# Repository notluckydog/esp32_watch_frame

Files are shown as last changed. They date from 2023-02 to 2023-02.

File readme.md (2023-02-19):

### 1. 项目说明

项目初衷：

某天突然发现了GC9A01这款1.28英寸的圆形TFT屏幕，正好当时在学习ESP32以及LVGL这款开源嵌入式GUI库，于是加在一起，自然而然就想到了做一款圆形手表。

项目定位：

demo项目，本意是用来验证esp32是否能够GC9A01这款1.28英寸屏幕，以及LVGL学习板(虽然最后并没有使用LVGL来实现该项目)。

项目功能：

1. 开机动画：在上电时播放开机动画，初始化例如网络信息的获取在此阶段完成
2. 多级菜单：分为三级菜单(如果把主页面和功能选择页面放在一级的话就是两级页面)，能够正常地进入和退出菜单，并能能够使用页面上提供的功能。
3. 天气信息：提供从今天起的未来三天的天气信息，并且展示在页面上，按下next按键时，展示下一天的天气信息，最多三天，按下menu按键，返回上一级菜单。
4. 计时功能：正计时、番茄钟(项目中未实现)、闹钟(项目中未实现)，按下ok按键，开始或者暂停计时，按下next按键时，复位并停止计时，按下menu返回上一级菜单。
5. 游戏功能：内置一款谷歌恐龙小游戏(仅绘制页面以及实现部分基本逻辑，未验证是否可行)。
6. 视频播放：播放badapple动画(TF卡功能未实现暂且放弃)。
7. 功能设置：对背光、网络信息更新频率、是否开启闹钟进行调整(其中背光和网络信息调整是滑动条，开启关闭闹钟用的是按钮)。

### 2. 目录结构  

- doc      ---用来存放相关datasheet等文档
- hardware  ---用来存放硬件部分原理图和PCB等文件
  - name_CAM  :gerber文件，发给PCB板厂
  - name_PRJ :工程文件，原理图以及PCB文件等
  - name_BOM :物料文件
  - name_ASM :贴片文件，发送给贴片厂
- model      ---用来存放外壳或者其他模型文件
- sofeware   ---用来存放软件等相关内容
  - lib     --用来存放外设的库文件等
  - esp32_watch(LVGL)   -- 使用LVGL来实现，但功能不全，可供参考
  - esp32_watch  --软件项目，使用TFT_eSPI库来绘制
- README.md    ---项目readme文件

### 3. 项目结构

**硬件**：

主控：ESP32-WROOM-32，240Mhz主频，蓝牙WIFI模块，4M FLASH；

屏幕：GC9A01驱动1.28英寸TFT；

锂电池充电：TP5400，单节锂电池充电，可升压至5V，最大充电电流1A；

指示灯：WS2812B，RGB三色，256级亮度显示(使用封装错误，故功能未实现)；

其他：一个TF卡座，一个5020封装的无源蜂鸣器，三个按键；

**软件**：

软件项目使用arduino平台进行开发，使用C++作为主要开发语言，其中，可以使用TFT_eSPI库来驱动TFT屏幕、FastLED库来驱动WS2812B、Bounces2库来实现按键功能，按键功能定义为 menu_button:返回上一级页面，next_button:显示同级的下一个内容，ok_button:确认选择，。

软件运行逻辑：

开机动画 - -> 硬件初始化 --> 主页面 - -> 按键动作 - - > 二级菜单 - - > 按键动作- - >三级菜单

其中，一级菜单：mian_ui 显示图片、星期、日记、时间等信息，并且监听按键动作，有任意按键动作则进入二级菜单；

二级菜单：list_ui 显示功能选择，监听动作，根据案件动作进入不同的页面；

三级页面： 

* weather_ui:显示天气信息，默认当天天气，按下next按键则显示下一天信息；
* clock_ui: 实现正计时功能，ok按键表示暂停或者开始，next按键表示重新开始，menu返回上一级；
* game_ui:实现游戏
* video_ui: 播放视频，或者可以实现电子相册功能
* net_ui: 进入该页面，配网程序自动开始，除非重新配网或者重启，否则不会重新工作；
* setup_ui:进行一些设置

多级菜单的实现：

在此仅指明我所了解的几种方式：

* 新建一个函数指针，在loop中运行该函数，在每一个页面监听按键的变化，根据按键的变化，将函数指针指向不同的函数，也是本项目使用的方式；
* 索引法：具体方式可查看该链接：https://blog.csdn.net/black_sneak/article/details/126442559?spm=1001.2014.3001.5506
* 链表法：维护一个链表，将菜单层级在该链表上实现

**模型** ：

暂未设计外壳。

### 4. 上手指南

项目采用VScode+platformio插件使用C++进行开发，VScode下载后需要下载C++插件、platformio插件，其中platformio因其服务器原因，在第一次新建项目时速度较慢，可以尝试使用手机热点或者科学上网的方式。

使用VScode打开项目，点击编译，下载，即可进行程序的下载。

在尝试复刻硬件项目时，可以考虑加入一颗USB转TTL芯片例如CP2012来做自动下载，这样方便后续调试，否则在下载时，在重新上电时需要将GPIO0对地短接，芯片才能进行烧录模式，烧录完成后重新上电，程序就能够正常运行。

在使用image2lcd对图片进行取模后，想要进行使用，需要将图片数组的类型改成uint16_t，并且使用推荐的ShowImage函数来绘制图片，原因是TFT_eSPI库对于图片的绘制与普通的有所不同。

演示画面可以查看该链接：https://www.bilibili.com/video/BV1F84y1p77C/?vd_source=fcd63c592e333153bb30b020f4c31b77

### 5. 不足点以及改进方向

**硬件**：

* 可以使用一颗USB转TTL芯片来做自动下载，手动将GPIO0对地短接对于下载过于麻烦；
* TF卡功能并没有实现，一开始怀疑是屏幕使用的SPI会对TF卡的SPI造成干扰，但是使用ESP32的开发板并没有发现该现象，怀疑是TF卡封装引脚画错了，TF卡对于该项目至关重要，因为彩色图片取模后的数据非常大，而不使用图片则失去了使用TFT屏幕的意义；
* 如果需要继续缩小体积，可以使用ESP32-pico-d4这款QFN的芯片，但是天线需要自己设计，不管是使用板载天线还是贴片陶瓷天线，都没有把握；
* 屏幕需要放在正面，因为屏幕排线较短，画板时没有考虑这一点，虽然使用没有太大影响，但是不美观，而且FPC上引脚也容易断；
* 锂电池充电IC可以使用TP4057这款SOT23-6封装的IC，并且将TP4057的CHRG引脚和PROG引脚接到ESP32上，判断这两个引脚的电平，则可以判断是否在充电和充电是否已完成。
* 如果仅仅需要三色灯的话，使用WS2812B时并不是特别需要，可以直接使用一个0603封装的贴片三色LED灯，或者将三个不同颜色的0603的LED灯放在一起。
* 板框可以画成两端突出，方便后续增加表带；

**软件**：

* 暂不清楚TFT_eSPI库的更新方式，所以有时候会出现，明明在改变函数指向时做了一次清屏操作，或者填充操作，但是该操作并未生效，只能在切换页面后，判断一次是不是需要做一次清屏操作然后做一次清屏操作；
* LVGL库是为触摸屏开发的，虽然提供了API来适配键盘和编码器，但是在使用时并不方便，做了多层封装以至于让人难以对具体的功能进行把握，且LVGL仅对单个页面，对于页面之间的切换，并没有提供一个思路或者方法，且LVGL占用空间实在是太大了，对于ESP32来说都有点捉襟见肘，所以本项目仅使用了TFT_eSPI库来对屏幕进行控制；
* 虽然使用了C++，但是并没有使用class的方式来进行书写，写法还是面向过程；

### 6. 贡献者及资料

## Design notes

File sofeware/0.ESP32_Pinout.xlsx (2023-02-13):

IO选择 | 对应功能 | IO编号 | 功能 | 启动项相关 | ADC | DAC | UART | Touch | SPI/IIC
 |  | GPIO0 |  | 下载：低电平/启动：高电平 | ADC2_1 |  |  | TP_1
 |  | GPIO1 | TX |  |  |  | TX0
 |  | GPIO2 |  |  | ADC2_2 |  |  | TP_2
 |  | GPIO3 | RX |  |  |  | RX0
 |  | GPIO4 |  |  | ADC2_0 |  |  | TP_0
 |  | GPIO5 | SD_CS | 启动时必须高电平 |  |  |  |  | VSPI
 |  | GPIO6 |  | 连接了FLASH(CLK)
 |  | GPIO7 |  | 连接了FLASH(SD0)
 |  | GPIO8 |  | 连接了FLASH(SD1)
 |  | GPIO9 |  | 连接了FLASH(SD2) |  |  | RX1
 |  | GPIO10 |  | 连接了FLASH(SD3) |  |  | TX1
 |  | GPIO11 |  | 连接了FLASH(CMD)
 |  | GPIO12 |  | 启动时必须低电平 | ADC2_5 |  |  | TP_5 | HSPI
 |  | GPIO13 |  |  | ADC2_4 |  |  | TP_4 | HSPI
 |  | GPIO14 | TFT_SCLK | 启动时必须高电平 | ADC2_6 |  |  | TP_6 | HSPI
 |  | GPIO15 | TFT_MOSI | 启动时必须高电平 | ADC2_3 |  |  | TP_3 | HSPI
 |  | GPIO16 | BT_MENU |  |  |  | RX2
 |  | GPIO17 | TFT_CS |  |  |  | TX2
 |  | GPIO18 | SD_SCLK |  |  |  |  |  | VSPI
 |  | GPIO19 | SD_MISO |  |  |  |  |  | VSPI
 |  | GPIO21 | BT_OK |  |  |  |  |  | IIC_SDA
 |  | GPIO22 | TFT_BLK |  |  |  |  |  | IIC_SCL
 |  | GPIO23 | SD_MOSI |  |  |  |  |  | VSPI
 |  | GPIO25 | BT_NEXT |  | ADC2_8 | DAC_1
 |  | GPIO26 | WS2812B |  | ADC2_9 | DAC_2
 |  | GPIO27 | TFT_DC |  | ADC2_7 |  |  | TP_7
 |  | GPIO32 |  |  | ADC1_4 |  |  | TP_9
 |  | GPIO33 | TFT_RST |  | ADC1_5 |  |  | TP_8
 |  | GPIO34 |  | Input Only | ADC1_6
 |  | GPIO35 |  | Input Only | ADC1_7
 |  | GPIO36 |  | Input Only/SVP | ADC1_0
 |  | GPIO39 |  | Input Only/SVN | ADC1_3
说明： 1. 使用Wi-Fi会与ADC2冲突，要注意！ 2. ADC的使用并非线性的，0-0.1V和3.2-3.3V区间就是有问题的！

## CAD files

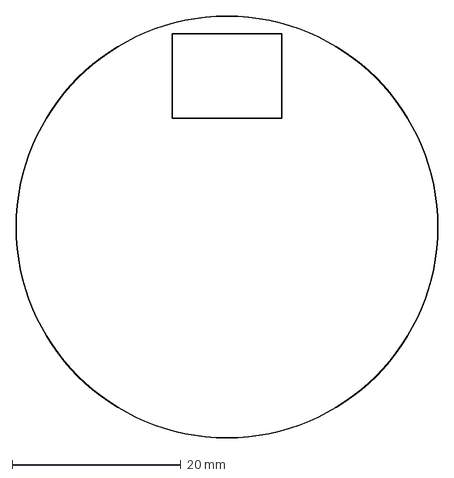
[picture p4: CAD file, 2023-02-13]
model/yuanxing1.dxf
50.0 x 50.0 mm

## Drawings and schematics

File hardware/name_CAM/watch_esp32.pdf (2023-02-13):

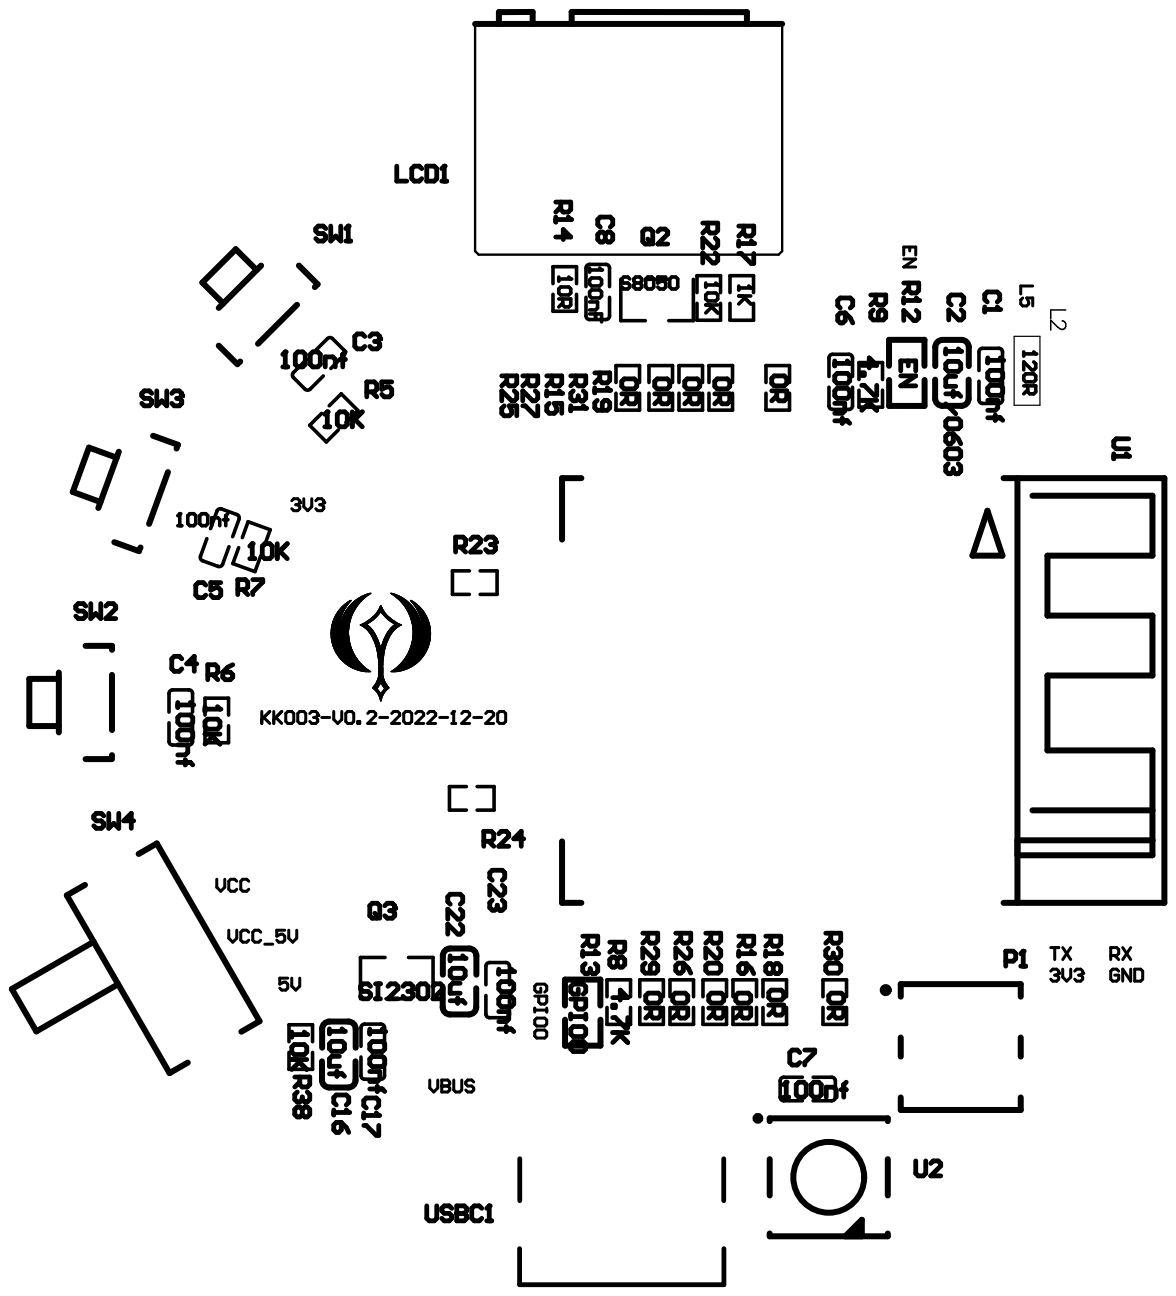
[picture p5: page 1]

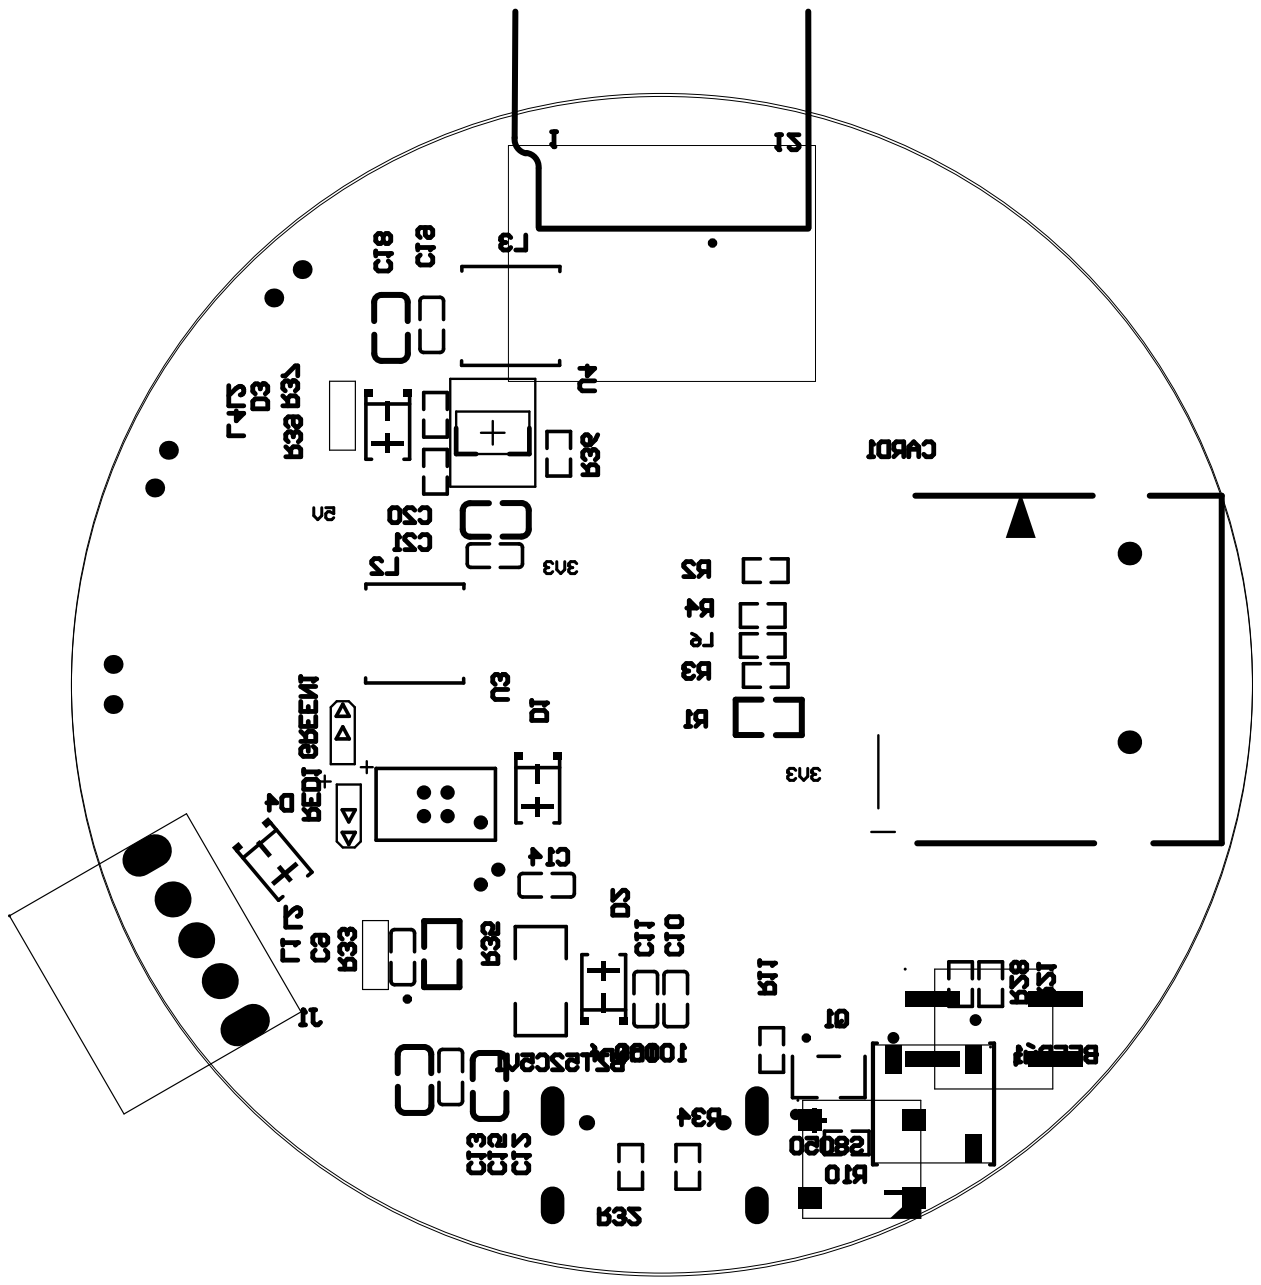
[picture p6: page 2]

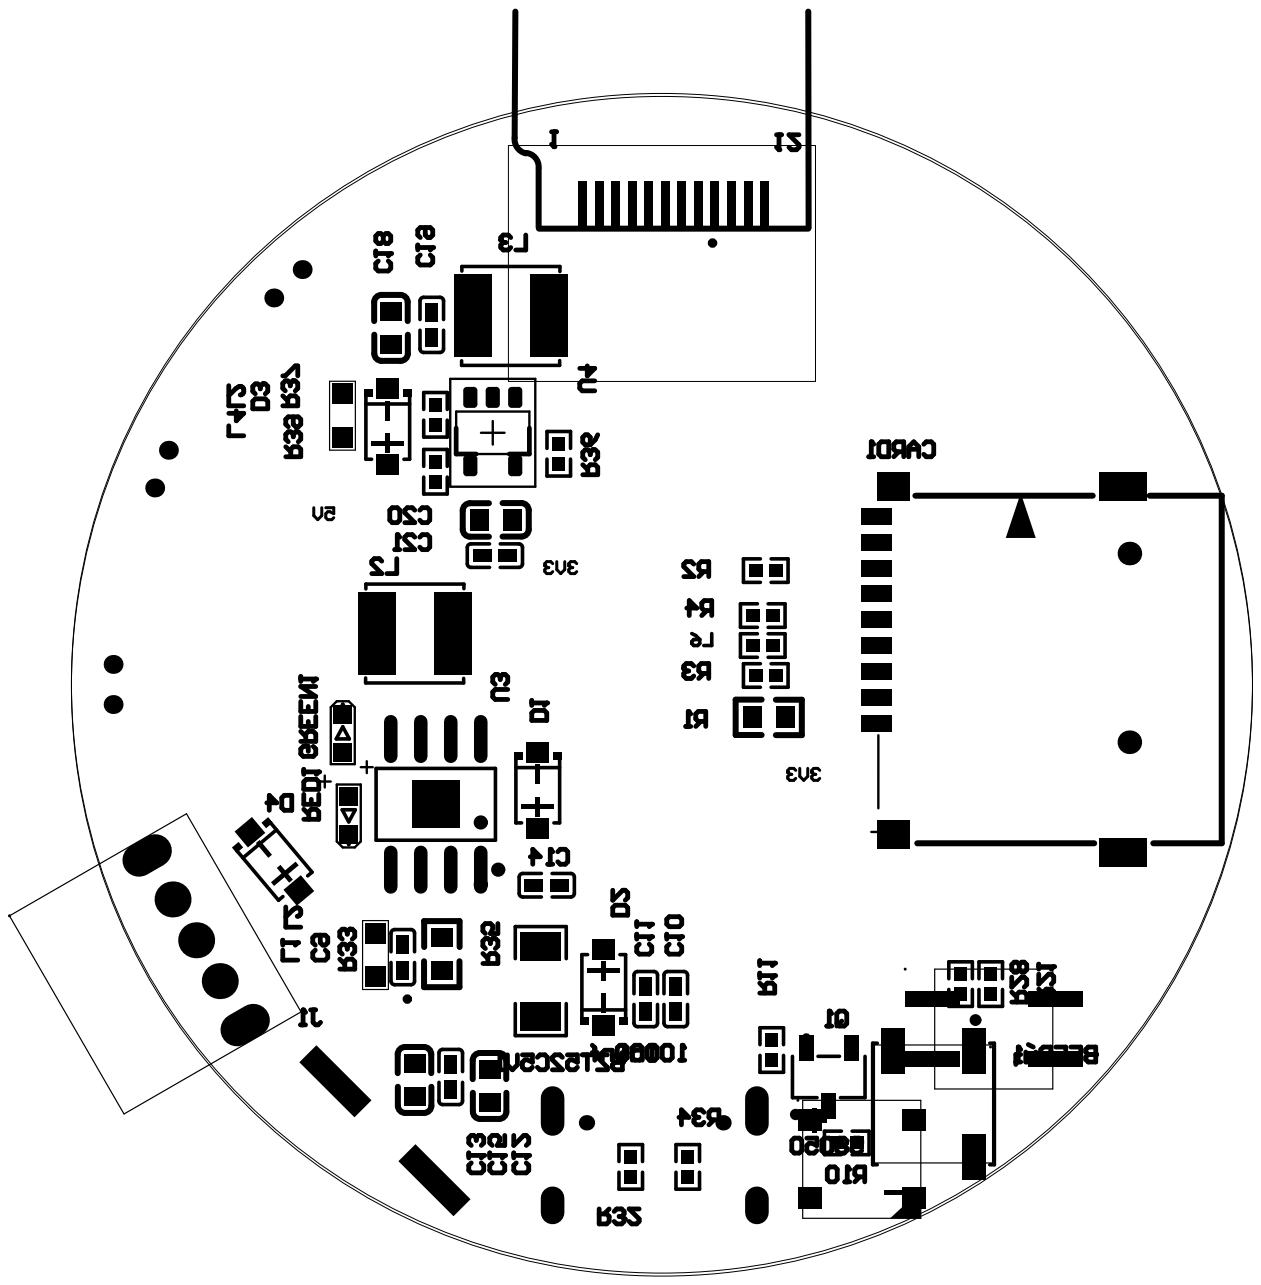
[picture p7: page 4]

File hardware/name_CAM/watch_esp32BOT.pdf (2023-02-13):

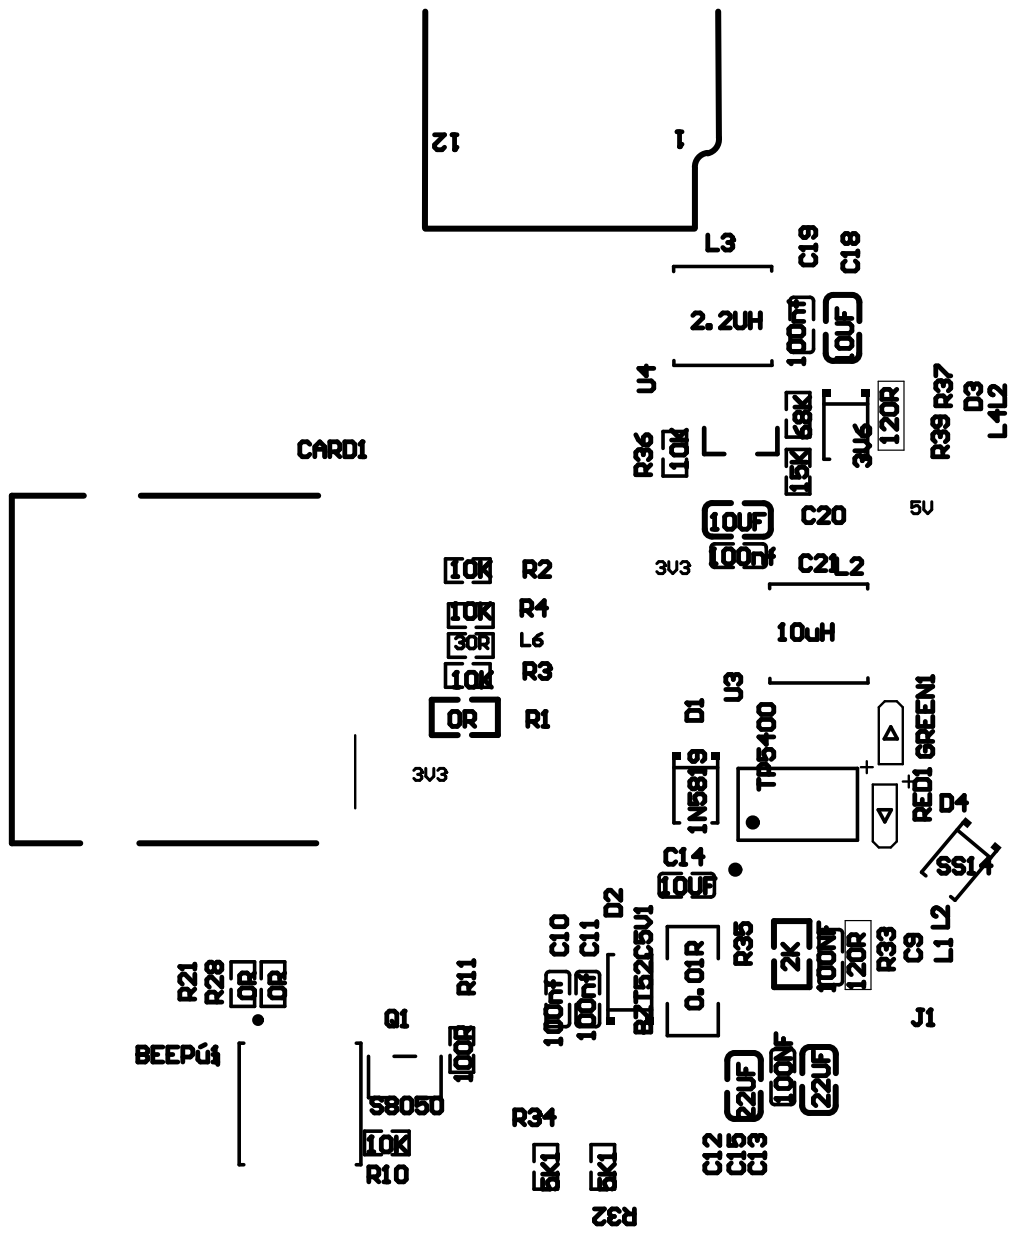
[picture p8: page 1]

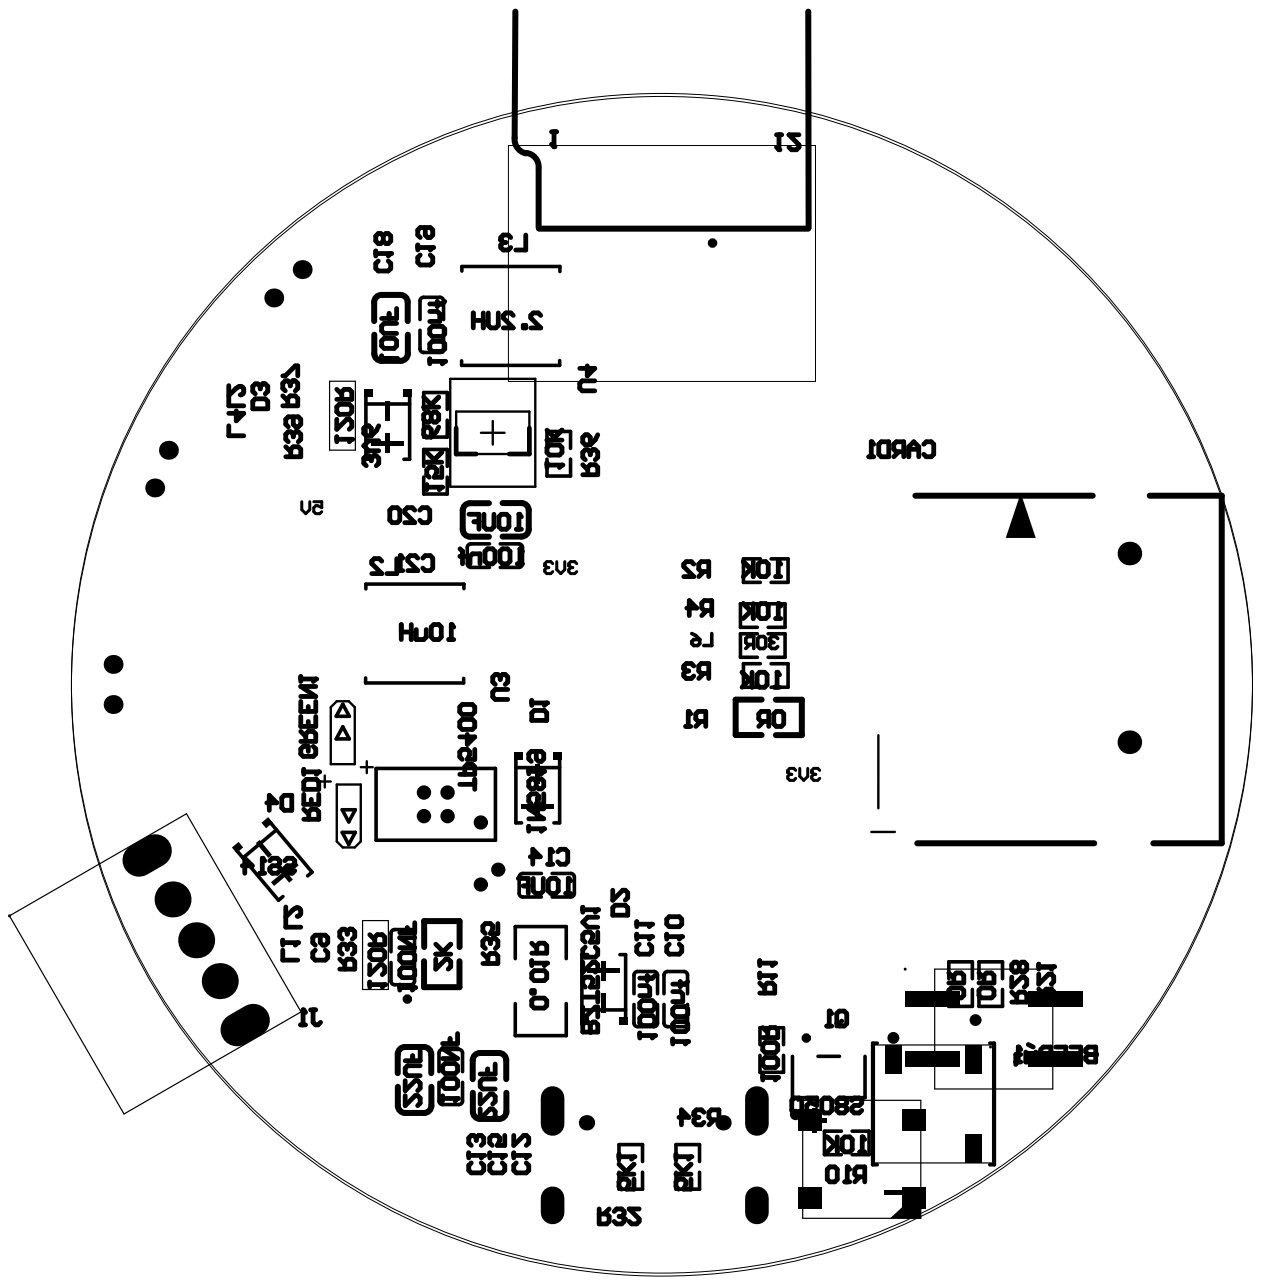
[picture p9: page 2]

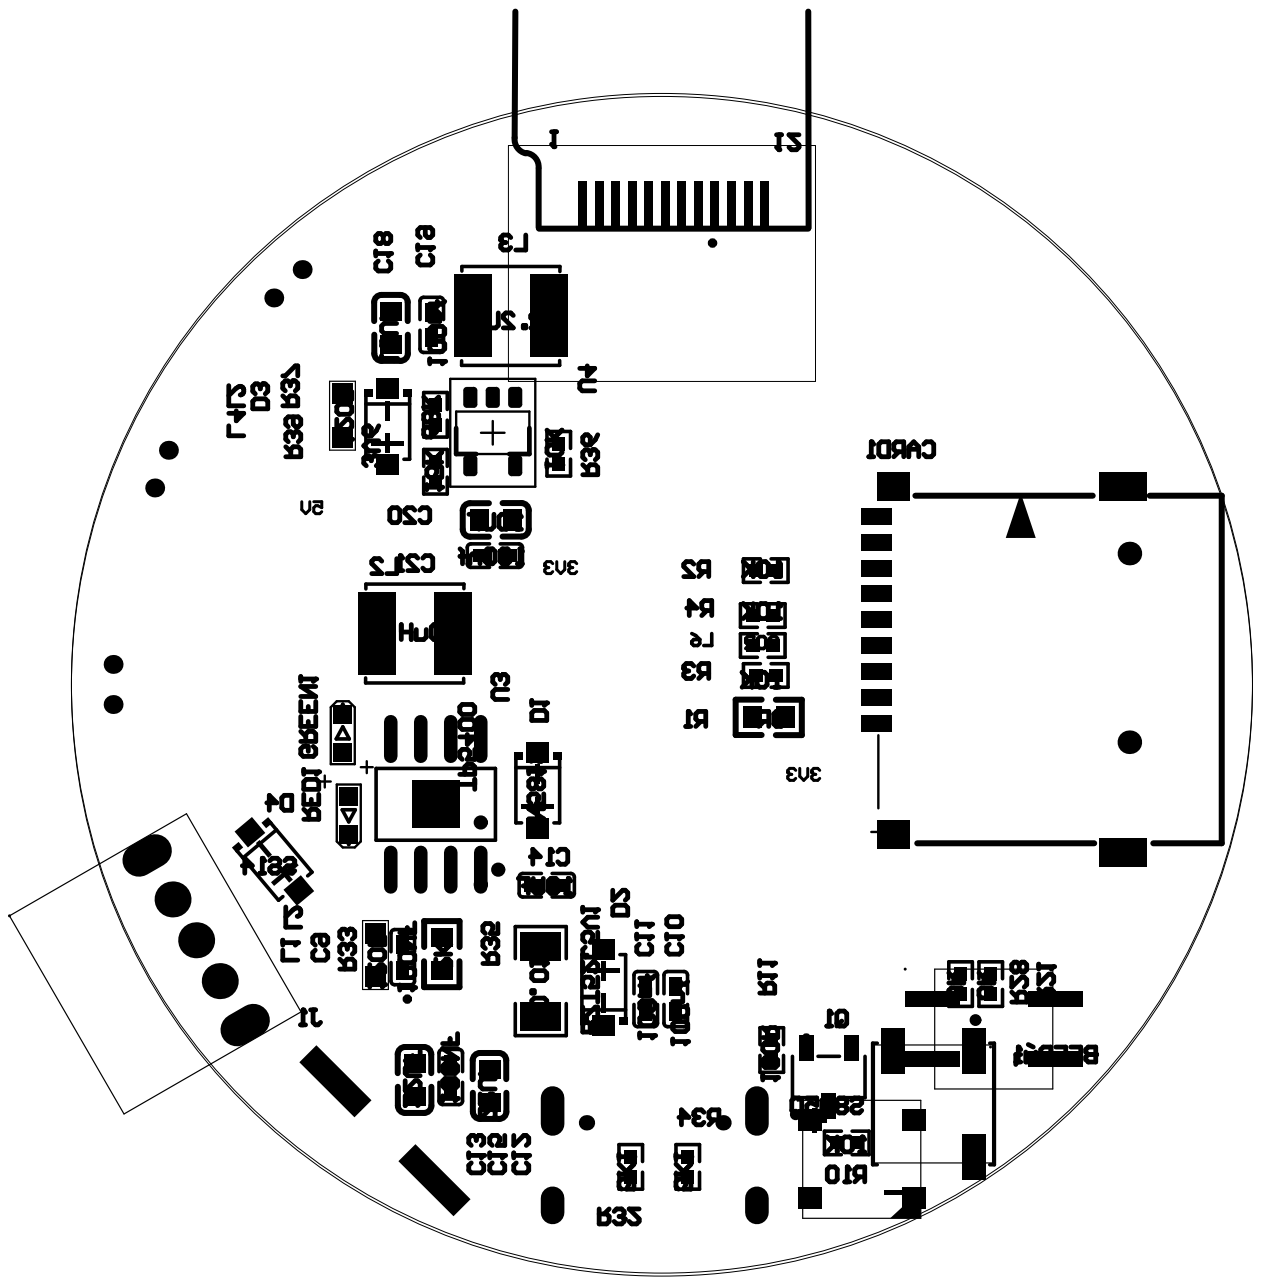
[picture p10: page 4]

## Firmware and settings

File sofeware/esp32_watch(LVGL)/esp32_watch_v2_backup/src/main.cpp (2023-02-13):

#include <Arduino.h>

//#include <FastLED.h>

#include <WiFi.h>

#include "button.h"
#include "beep.h"

#include "SetWiFi.h"

#include "my_weather.h"

#include "ntp_time.h"

//#include "my_SD.h"

#include <lvgl.h>
//#include "lv_examples.h"
#include <TFT_eSPI.h> // Hardware-specific library
#include <SPI.h>

#include "ui/my_style.h"

#include "ui/ui_manage.h"

#include "my_wifi.h"


//#include "sd_card.h"

// #include "FS.h"
// #include "SD.h"
// #include "SPI.h"

// #include "SD_test.h"

#include "my_SD.h"
//#include "SD.h"


#define BEEP_PIN 32

uint8_t BT_MENU_PIN=16;
uint8_t BT_OK_PIN=21;
uint8_t BT_NEXT_PIN=25;


uint8_t freq = 5000;
uint8_t ledChannel =0;
uint8_t resolution = 8;
uint8_t dutyCycle = 100;

lv_indev_t* indev_keypad;



#define TFT_GREY 0x5AEB

TFT_eSPI tft = TFT_eSPI();       // Invoke custom library

/*Change to your screen resolution*/
static const uint16_t screenWidth  = 240;
static const uint16_t screenHeight = 240;

static lv_disp_draw_buf_t draw_buf;
static lv_color_t buf[ screenWidth * 10 ];

lv_obj_t * a_ui;
lv_obj_t * main_Screen;//主页面，home页
lv_obj_t * list_Screen;//二级菜单选择页面，
lv_obj_t * weather_ico_Screen;  //二级选择页面 天气
lv_obj_t * clock_ico_Screen; // 二级选择页面 计时器、
lv_obj_t * tomato_ico_Screen;  //二级选择页面 番茄钟
lv_obj_t * aralm_ico_Screen; //二级选择页面，闹钟
lv_obj_t * setting_ico_Screen; //二级选择页面 设置
lv_obj_t*  net_ico_Screen;  // 二级页面 配网二维码
lv_obj_t * weather_Screen;    //三级页面  天气
lv_obj_t * clock_Screen;   // 三级页面 计时器
lv_obj_t * aralm_Screen;  //三级页面 闹钟，暂不提供闹钟设置
lv_obj_t * tomato_Screen; //三级页面 番茄钟 35min/10min
lv_obj_t * setting_Screen; // 三级页面 设置 ，暂时只提供选择，不做具体功能
lv_obj_t * net_Screen;//三级页面 配网二维码
lv_obj_t * logo_Screen;

//SdCard tf;

struct tm timeinfo;


bool setWiFi_Flag = false;

// uint8_t ui_index = 0;// 用来记录当前UI所在的位置
// uint8_t ui_index_last =0; // 用来记录上一次UI所在的位置
// extern  Menu_table table[10] ;

Button menu_button(BT_MENU_PIN);
Button ok_button(BT_NEXT_PIN);
Button next_button(BT_OK_PIN);


Beep beep(BEEP_PIN,freq,ledChannel);

//TFT_eSPI tft = TFT_eSPI(screenWidth, screenHeight); /* TFT instance */

#if LV_USE_LOG != 0
/* Serial debugging */
void my_print(const char * buf)
{
    Serial.printf(buf);
    Serial.flush();
}
#endif

/* Display flushing */
void my_disp_flush( lv_disp_drv_t *disp, const lv_area_t *area, lv_color_t *color_p )
{
    uint32_t w = ( area->x2 - area->x1 + 1 );
    uint32_t h = ( area->y2 - area->y1 + 1 );

    tft.startWrite();
    tft.setAddrWindow( area->x1, area->y1, w, h );
    tft.pushColors( ( uint16_t * )&color_p->full, w * h, true );
    tft.endWrite();

    lv_disp_flush_ready( disp );
}

//按键扫描函数
uint8_t key_scan(){
  //menu按键被按下
    if(menu_button.getStatus()==1){
      return 1;
    }

  //ok按键被按下
  if(ok_button.getStatus()==1){
      return 2;
    }

  //next按键被按下
  if(menu_button.getStatus()==1){
      return 3;
    }

    return 0;

}
//按键状态更新函数
static void key_read(lv_indev_drv_t * indev_driver, lv_indev_data_t * data){
    static uint32_t last_key = 0;
	  uint32_t act_key = key_scan();

    if(act_key != 0) {
      data->state = LV_INDEV_STATE_PR;
	    switch(act_key) {
	        case 1:
              //menu按键
	            //act_key = LV_KEY_PREV;
	            //data->state = LV_INDEV_STATE_PRESSED;	
	            break;
              //OK 按键
	        case 2:
	            act_key = LV_KEY_NEXT;
	            //data->state = LV_INDEV_STATE_RELEASED;
	            //data->enc_diff++;
	            break;
              //next按键
	        case 3:
	            act_key = LV_KEY_ENTER;
	            //data->state = LV_INDEV_STATE_RELEASED;
	            //data->enc_diff--;
	            break;
	    }
	    last_key = act_key;
	}else{
    data->state = LV_INDEV_STATE_REL;
  }
	data->key = last_key;

  //return false;


}


//LVGL 初始化
void MyDispalyInit(){
    lv_init();

#if LV_USE_LOG != 0
    lv_log_register_print_cb( my_print ); /* register print function for debugging */
#endif

    tft.begin();          /* TFT init */
    tft.setRotation( 0 ); /* Landscape orientation, flipped */
    tft.fillScreen(TFT_BLACK);//清屏

    lv_disp_draw_buf_init( &draw_buf, buf, NULL, screenWidth * 10 );

    /*Initialize the display*/
    static lv_disp_drv_t disp_drv;
    lv_disp_drv_init( &disp_drv );
    /*Change the following line to your display resolution*/
    disp_drv.hor_res = screenWidth;
    disp_drv.ver_res = screenHeight;
    disp_drv.flush_cb = my_disp_flush;
    disp_drv.draw_buf = &draw_buf;
    disp_drv.sw_rotate = 1;
    disp_drv.rotated = LV_DISP_ROT_180;
    lv_disp_drv_register( &disp_drv );

    /*Initialize the (dummy) input device driver*/
    static lv_indev_drv_t indev_drv;
    lv_indev_drv_init( &indev_drv );
    //实体按键初始化
    //lv_port_indev_init();
    //indev_drv.type = LV_INDEV_TYPE_POINTER;
    //ndev_drv.read_cb = my_touchpad_read;
    indev_drv.type = LV_INDEV_TYPE_KEYPAD;
    //indev_drv.read_cb = key_read;
    indev_keypad = lv_indev_drv_register( &indev_drv );

}



//连接wifi
void my_connect_wifi(){
     WiFi.begin("UTF-8", "2664856778"); //连接网络
  while (WiFi.status() != WL_CONNECTED) //等待网络连接成功
  {
    delay(500);
    Serial.print(".");
  }
  Serial.println("WiFi connected!");

  Serial.println("IP address: ");
  Serial.println(WiFi.localIP()); //打印模块IP


}

/*   硬件初始化 */
void BSP_init(){
  //beep.setDutyCycle(100);
  menu_button.init();
  ok_button.init();
  next_button.init();
  my_connect_wifi();
  //getLocalTime();

  MyDispalyInit();
  ui_init();

  Serial.print("hardware init succuss! \n\n");
  //tf.init();
}

//配网
void setWifi(){
    initBasic();
    initSoftAP();
    initWebServer();
    initDNS();

    while(setWiFi_Flag == true) {
    server.handleClient();
    dnsServer.processNextRequest();
    if(WiFi.status() == WL_CONNECTED) {
      server.stop();
      setWiFi_Flag = true;
    }
  }
}







void setup() {
  // put your setup code here, to run once:

 
  delay(1000);
  Serial.begin(115200);


  BSP_init();
  //lv_example_btn_1();
  


}

char time_text1[10];
void loop() {
  
  
  Serial.print("very good !\n\n");
//   delay(1000);

  //SD_TEST();
  //lv_timer_handler(); /* let the GUI do its work */
  //button_task();
  //ui_manage();

  getLocalTime();
  
  strftime(time_text1,sizeof(time_text1),"%H:%M:%S",&timeinfo);
  Serial.printf("time_text will be \n\n");
  Serial.print(time_text1);
  Serial.print("\n");
  delay(1000);
  delay(1000);
  delay(1000);
  delay(1000);
  delay(1000);
  delay( 5 );



  



}

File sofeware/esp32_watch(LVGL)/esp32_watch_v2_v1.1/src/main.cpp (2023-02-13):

#include <Arduino.h>

//#include <FastLED.h>

#include <WiFi.h>

#include "button.h"
#include "beep.h"

#include "SetWiFi.h"

#include "my_weather.h"

#include "ntp_time.h"

//#include "my_SD.h"


#include "ui/ui_init.h"

#include "ui/my_style.h"

#include "ui/ui_manage.h"

#include "my_wifi.h"


//#include "sd_card.h"

// #include "FS.h"
// #include "SD.h"
// #include "SPI.h"

// #include "SD_test.h"

//#include "my_SD.h"
//#include "SD.h"


#define BEEP_PIN 32

uint8_t BT_MENU_PIN=16;
uint8_t BT_OK_PIN=21;
uint8_t BT_NEXT_PIN=25;

uint32_t freq = 5000;
uint8_t ledChannel =0;
uint8_t resolution = 8;
uint8_t dutyCycle = 100;


lv_obj_t * a_ui;
lv_obj_t * main_Screen;//主页面，home页
lv_obj_t * list_Screen;//二级菜单选择页面，
lv_obj_t * weather_ico_Screen;  //二级选择页面 天气
lv_obj_t * clock_ico_Screen; // 二级选择页面 计时器、
lv_obj_t * tomato_ico_Screen;  //二级选择页面 番茄钟
lv_obj_t * aralm_ico_Screen; //二级选择页面，闹钟
lv_obj_t * setting_ico_Screen; //二级选择页面 设置
lv_obj_t*  net_ico_Screen;  // 二级页面 配网二维码
lv_obj_t * weather_Screen;    //三级页面  天气
lv_obj_t * clock_Screen;   // 三级页面 计时器
lv_obj_t * aralm_Screen;  //三级页面 闹钟，暂不提供闹钟设置
lv_obj_t * tomato_Screen; //三级页面 番茄钟 35min/10min
lv_obj_t * setting_Screen; // 三级页面 设置 ，暂时只提供选择，不做具体功能
lv_obj_t * net_Screen;//三级页面 配网二维码
lv_obj_t * logo_Screen;

//SdCard tf;

struct tm timeinfo;   //当前时间
struct tm aralm_timeinfo;  //设定的闹钟时间

bool setWiFi_Flag = false; // 标识是否需要配网，当第一次开机和ui进入配网页面的时候需要重新配网

time_t last_time;

Beep beep(BEEP_PIN,freq,ledChannel);

/*创建任务句柄   */
static TaskHandle_t AppTaskCreate_Handle = NULL;  // 创建任务 任务句柄
static TaskHandle_t GUI_task_handle = NULL;   // GUI 任务
static TaskHandle_t GUI_time_update_task_handle = NULL;  //LVGL 主页面更新时间 例如20:20:20
static TaskHandle_t GUI_day_update_task_handle = NULL; // LVGL 主页面日期更新 2022-10-10
static TaskHandle_t GUI_weekday_update_task_handle = NULL;  //LVGL 主页面 星期更新
static TaskHandle_t GUI_weather_update_task_handle = NULL;  //LVGL 主页面 天气情况更新
static TaskHandle_t GUI_three_weather_update_task_handle = NULL;  // 次级页面 近三天天气状况更新
static TaskHandle_t GUI_countting_update_task_handle = NULL;  // 次级页面 计时器任务
static TaskHandle_t GUI_aralm_update_task_handle = NULL;   //闹钟任务


//void GUI_time_update_task(void *p);
//连接wifi
void my_connect_wifi(){
     WiFi.begin("UTF-8", "2664856778"); //连接网络
  while (WiFi.status() != WL_CONNECTED) //等待网络连接成功
  {
    delay(500);
    Serial.print(".");
  }
  Serial.println("WiFi connected!");

  Serial.println("IP address: ");
  Serial.println(WiFi.localIP()); //打印模块IP

}

//断开网络
void my_disconnect_wifi(){
    WiFi.disconnect(true);
    WiFi.mode(WIFI_OFF);
    Serial.println("WiFi disconnected!");

}


void GUI_Task(void *p){
  while(1){

    lv_timer_handler(); /* let the GUI do its work */
  //button_task();
  //ui_manage();

  vTaskDelay(5);
    //delay( 5 );
  }
  
  
}

//用来每一个小时更新一次天气、时间等信息
void net_info_update_task(void *p){

      while(1){
        
        double seconds = difftime(mktime(&timeinfo),last_time);
        if(seconds<30){
            my_connect_wifi();
            getLocalTime();
            //getWeatherInfo();
            getThreeDayWeather();
            my_disconnect_wifi();

        };
      }

}

//设置闹钟
void set_aralm(){
      aralm_timeinfo.tm_hour = 10;
      aralm_timeinfo.tm_min  = 20;
      aralm_timeinfo.tm_sec  = 00;
}
//闹钟任务，到了时间就
void aralm_task(void *p){

  while(1){
    if(timeinfo.tm_hour ==aralm_timeinfo.tm_hour&&timeinfo.tm_min==aralm_timeinfo.tm_min){
      beep.setDutyCycle(100);
    }
  }
}


/*   硬件初始化 */
void BSP_init(){
  //beep.setDutyCycle(100);
  pinMode(BT_MENU_PIN,INPUT_PULLUP);
  pinMode(BT_NEXT_PIN,INPUT_PULLUP);
  pinMode(BT_OK_PIN,INPUT_PULLUP);
  // menu_button.init();
  // ok_button.init();
  // next_button.init();
  my_connect_wifi();
  getLocalTime();
  //getWeatherInfo();
  getThreeDayWeather();
  my_disconnect_wifi();

  last_time = time(0);

  MyDispalyInit();
  ui_init();


  Serial.print("hardware init succuss! \n\n");
  //tf.init();
}




void setup() {
  // put your setup code here, to run once:

 
  delay(1000);
  Serial.begin(115200);


  BSP_init();

  xTaskCreate(GUI_Task,"time update",1024*20,NULL,1,NULL);
  xTaskCreate(GUI_time_update_task,"time update",1024*4,NULL,1,NULL);
  //lv_example_btn_1();
  


}

// char time_text1[10];
// strftime(time_text1,sizeof(time_text1),"%H:%M:%S",&timeinfo);
void loop() {
  
  
  // Serial.print("very good !\n\n");
  // delay(1000);

  // //SD_TEST();
  // lv_timer_handler(); /* let the GUI do its work */
  // //button_task();
  // //ui_manage();

  // delay( 5 );



  



}
